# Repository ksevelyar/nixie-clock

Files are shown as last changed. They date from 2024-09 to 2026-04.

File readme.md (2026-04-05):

# Nixie Clock 

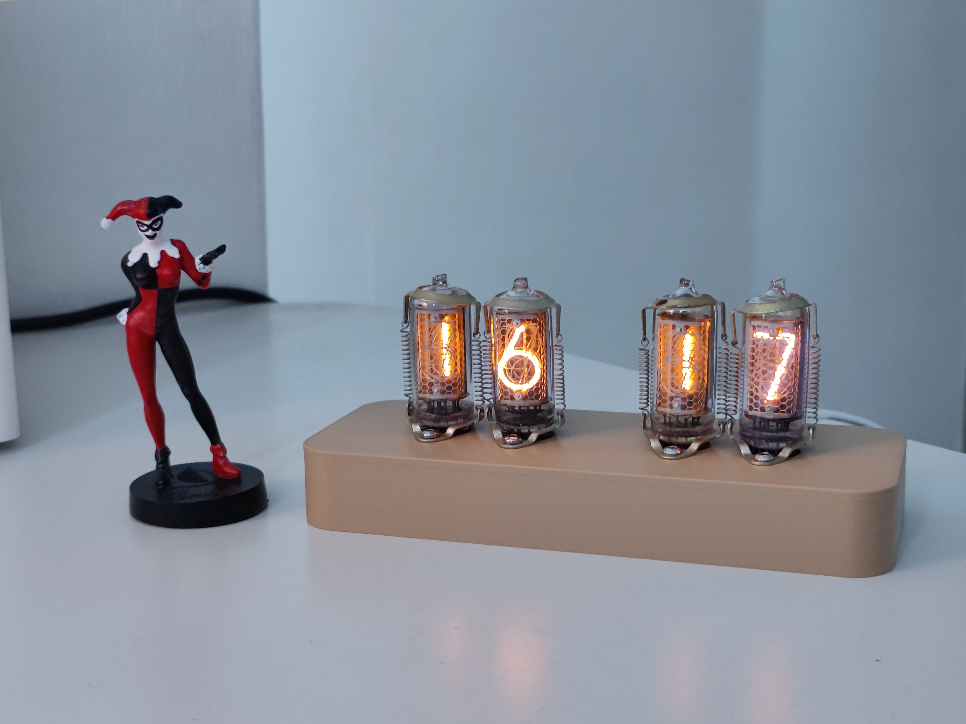
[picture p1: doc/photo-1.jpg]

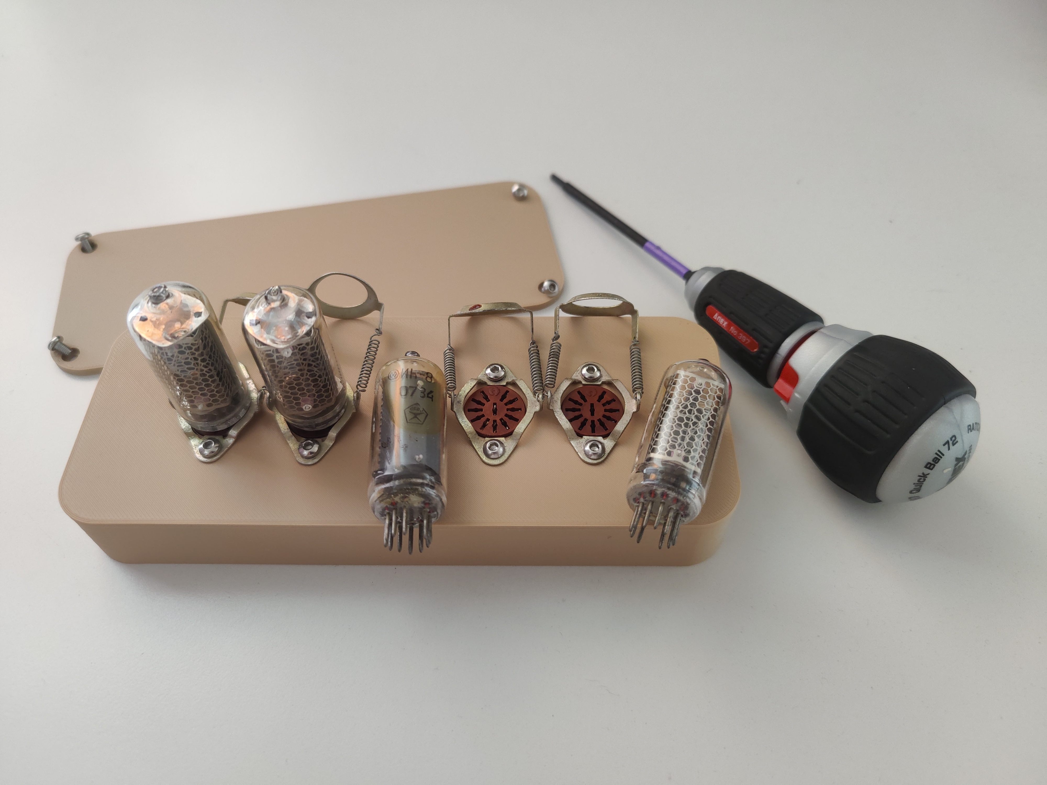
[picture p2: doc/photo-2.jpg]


## Features
- Keeps time in sync via SNTP over Wi‑Fi
- Socketed tubes for quick replacement
- 3D‑printed case
- RISC‑V mcu
- std Rust

## How it works
- On boot, connects to Wi‑Fi and starts SNTP.
- The main loop reads UNIX time, formats HH:MM, and multiplexes four digits.
- GPIO 0–3 carry BCD; GPIO 4–7 select the active digit (one high at a time).
- ~2 ms per digit yields flicker‑free display.

### BCD
```
0 → 0000
1 → 0001
2 → 0010
3 → 0011
4 → 0100
5 → 0101
6 → 0110
7 → 0111
8 → 1000
9 → 1001
```

## Hardware

### Schematic
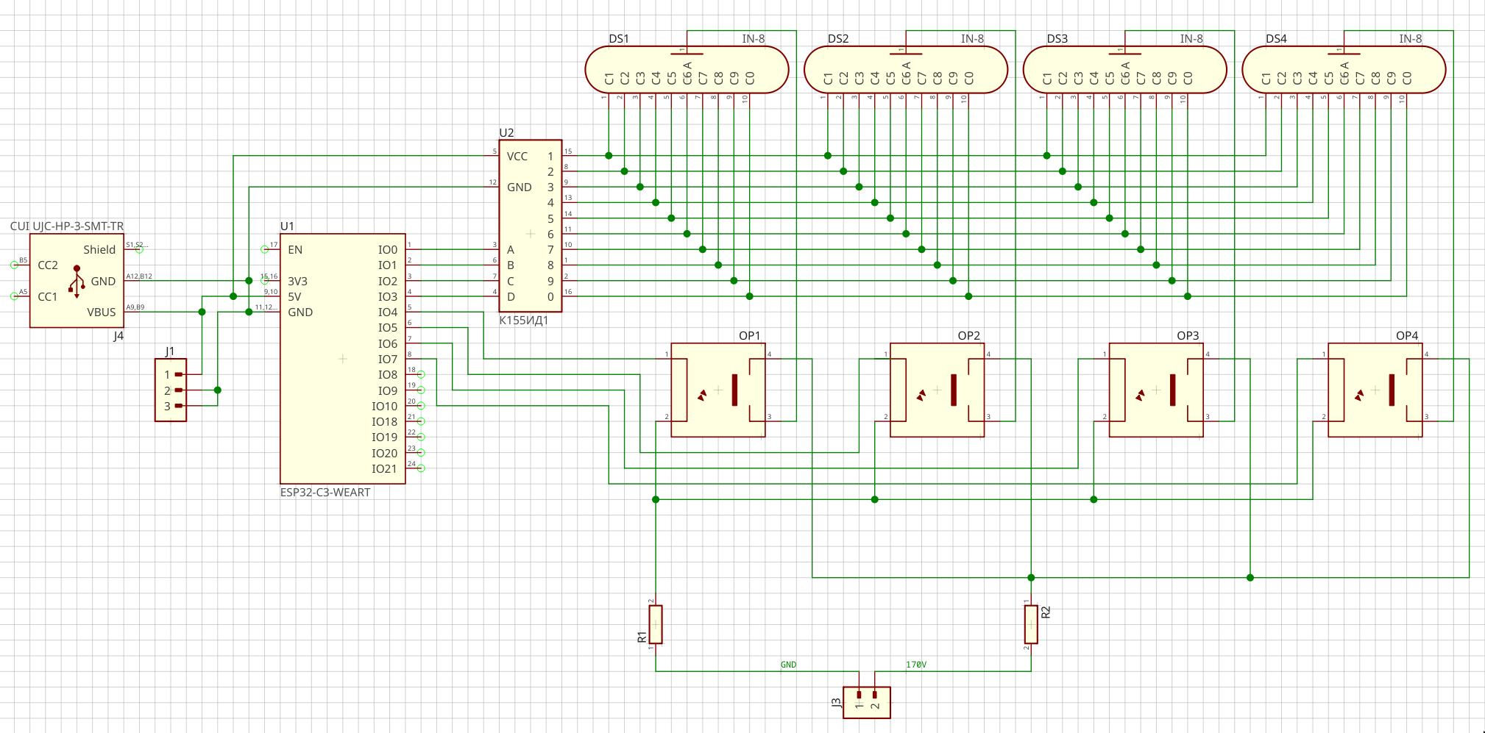
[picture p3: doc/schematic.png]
Schematic


### PCB
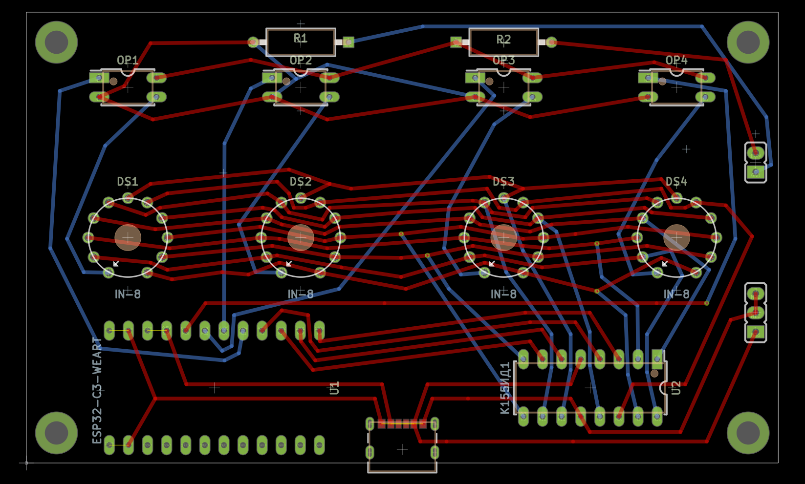
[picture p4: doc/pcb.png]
PCB


## Build & Flash

```fish
nix develop

SSID="WiFi" PASS="Password" UTC_OFFSET=180 cargo run --release
```
```
   Compiling nixie-clock v0.2.0 (/home/ksevelyar/code/nixie-clock)
    Finished `release` profile [optimized] target(s) in 0.67s
     Running `espflash flash --monitor target/riscv32imc-esp-espidf/release/nixie-clock`
[2026-03-31T20:32:43Z INFO ] Serial port: '/dev/ttyACM0'
[2026-03-31T20:32:43Z INFO ] Connecting...
[2026-03-31T20:32:43Z INFO ] Using flash stub
Chip type:         esp32c3 (revision v0.4)
Crystal frequency: 40 MHz
Flash size:        4MB
Features:          WiFi, BLE
MAC address:       60:55:f9:af:93:2c
App/part. size:    1,021,520/4,128,768 bytes, 24.74%
[2026-03-31T20:32:43Z INFO ] Segment at address '0x0' has not changed, skipping write
[2026-03-31T20:32:43Z INFO ] Segment at address '0x8000' has not changed, skipping write
[00:00:12] [========================================]     599/599     0x10000                           [2026-03-31T20:32:57Z INFO ] Flashing has completed!
Commands:
    CTRL+R    Reset chip
    CTRL+C    Exit

...

I (4346) nixie_clock: Wifi DHCP info: IpInfo { ip: 192.168.1.114, subnet: Subnet { gateway: 192.168.1.1, mask: Mask(24) }, dns: Some(192.168.1.1), secondary_dns: Some(0.0.0.0) }

...

I (4366) nixie_clock: SNTP initialized
```

## Update deps
The simplest way is to regenerate a dummy project and copy the dependencies from it:

```
cargo generate esp-rs/esp-idf-template cargo
```

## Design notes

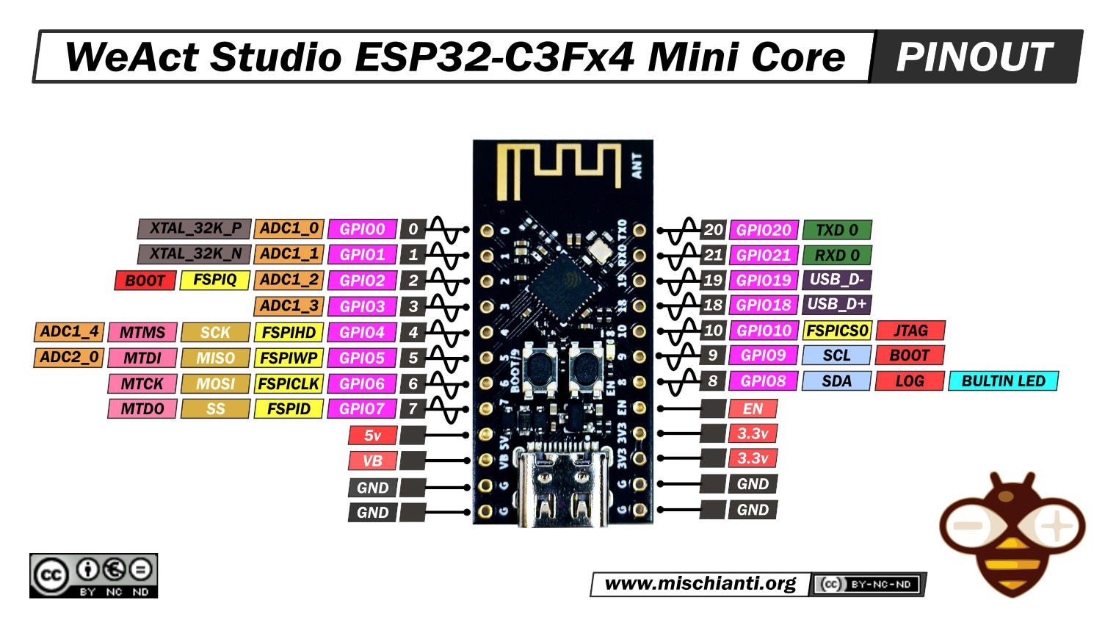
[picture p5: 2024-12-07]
doc/WeAct-Studio-ESP32-C3Fx4-pinout.jpg

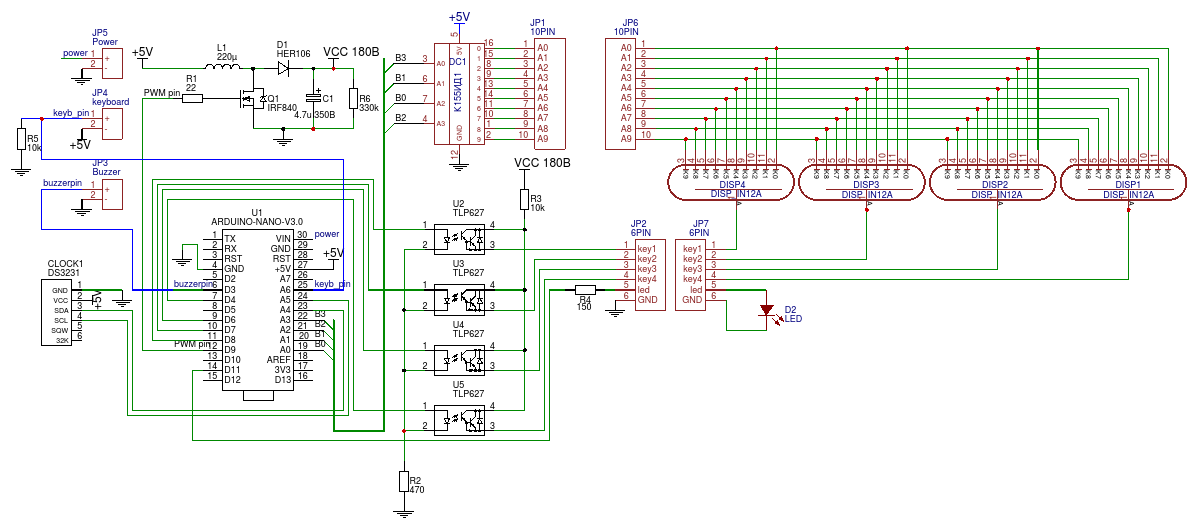
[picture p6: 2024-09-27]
esp32-std/doc/clock-2.png

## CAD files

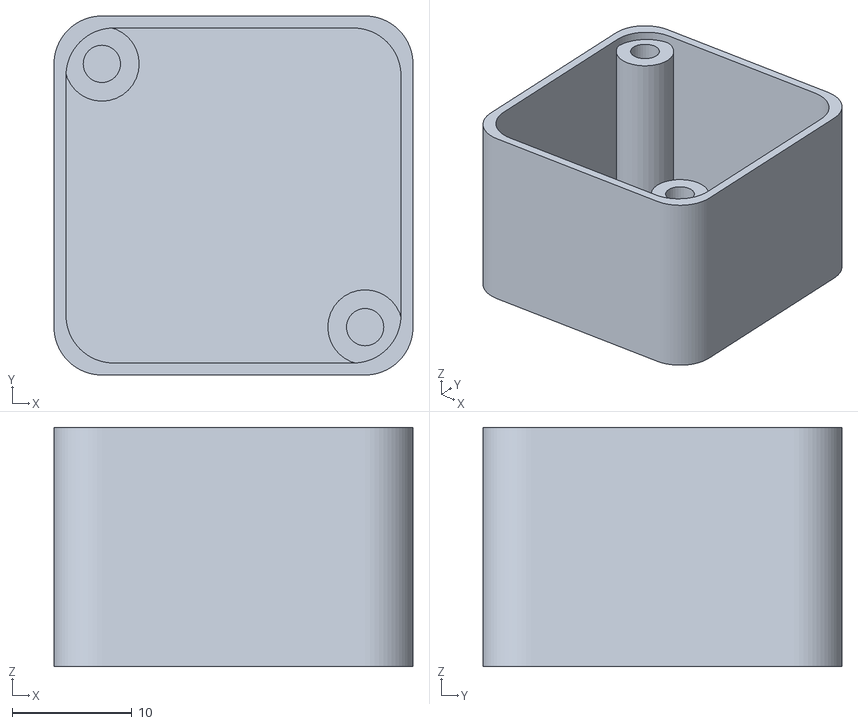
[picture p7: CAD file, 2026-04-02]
case/debug.stl
30.0 x 30.0 x 20.0

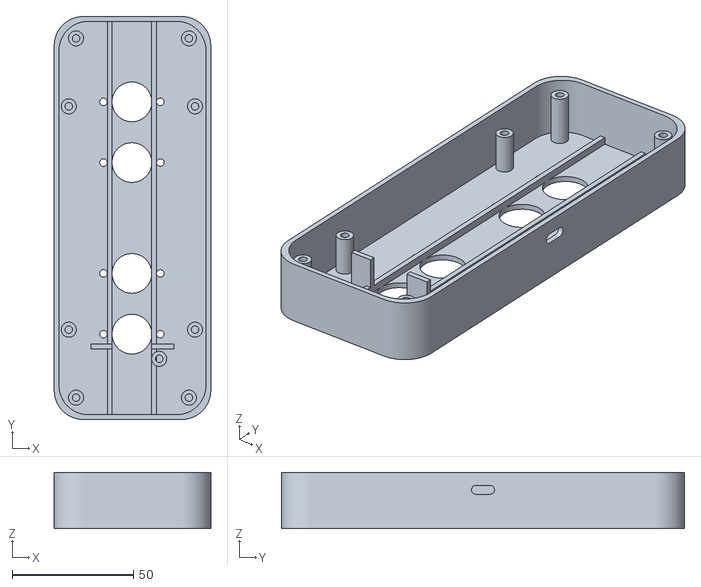
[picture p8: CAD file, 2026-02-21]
case/case.stl
64.5 x 166.0 x 23.2

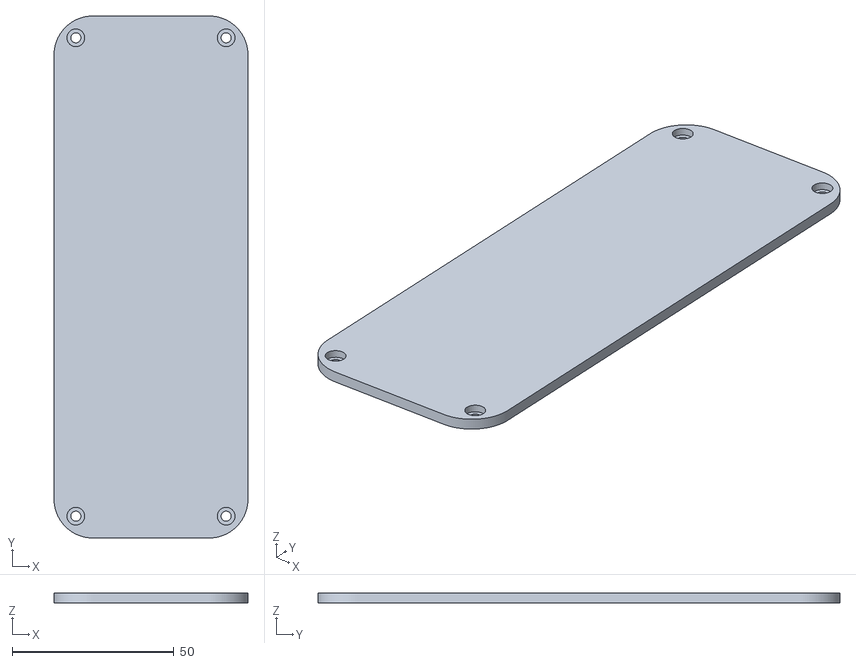
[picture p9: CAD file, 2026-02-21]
case/lid.stl
60.0 x 161.5 x 3.00

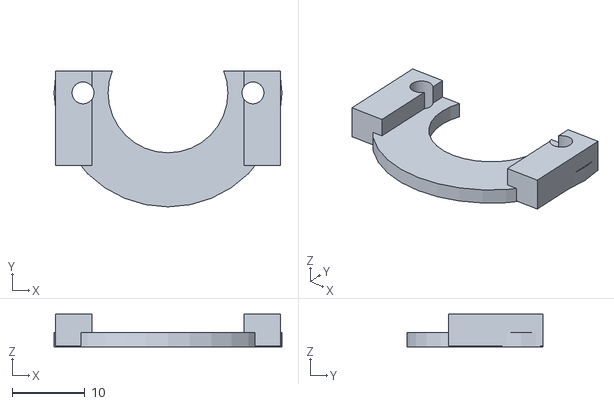
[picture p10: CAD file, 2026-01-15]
case/socket-mount.stl
31.4 x 18.7 x 4.50

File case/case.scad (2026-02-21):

include <mixin.scad>

$fn = 128;

module board() {
  color("#8ec5ff") {
    translate([4, 4, 0]) leg(board_leg_height);
    translate([board_width - 4, 4, 0]) leg(board_leg_height);
    translate([board_width - 4, board_length - 4, 0]) leg(board_leg_height);
    translate([4, board_length - 4, 0]) leg(board_leg_height);
  }
}

module leg(leg_height) {
  difference() {
    cylinder(h=leg_height, d=6.24, $fn=32);
    cylinder(h=leg_height + 1, d=3.12, $fn=32);
  }
}

module tube() {
  translate([board_width / 2, 0, -1])
    cylinder(h=45, d=tube_diameter, $fn=32);

  translate([board_width / 2 + 11.7, 0, -1])
    cylinder(h=45, d=m3, $fn=32);

  translate([board_width / 2 - 11.7, 0, -1])
    cylinder(h=45, d=m3, $fn=32);
}

module tubes() {
  socket_radius = socket_diameter / 2;

  end_gap = (enclosure_length - 4 * socket_diameter) / 3;
  pair_pitch = socket_diameter;

  first_pair_first_center = end_gap + socket_radius;
  second_pair_first_center = first_pair_first_center + 2 * pair_pitch + end_gap;

  tube_centers_y = [
    first_pair_first_center,
    first_pair_first_center + pair_pitch,
    second_pair_first_center,
    second_pair_first_center + pair_pitch,
  ];

  for (center_y = tube_centers_y) translate([0, center_y]) tube();
}

module type_c_cutout() {
  hull() {
    translate(
      [-5, enclosure_length / 2 + 2.9, board_leg_height]
    )
      rotate([0, 90, 0]) cylinder(h=10, d=3.7, $fn=64);
    translate(
      [-5, enclosure_length / 2 - 2.9, board_leg_height]
    )
      rotate([0, 90, 0]) cylinder(h=10, d=3.7, $fn=64);
  }
}

module enclosure() {
  color("#9b8cff") {
    translate([(enclosure_width + wall * 2) / 2 - tube_diameter / 2 - wall - 0.2, wall, 0.1]) cube([2, enclosure_length, 4.6]);
    translate([(enclosure_width - wall / 2) / 2 + tube_diameter / 2 + wall + 0.2, wall, 0.1]) cube([2, enclosure_length, 4.6]);

    difference() {
      rounded_box(
        [enclosure_width + wall * 2, enclosure_length + wall * 2, enclosure_height + lid_height + 0.2],
        r=corner_radius
      );
      translate([wall, wall, wall]) rounded_box(
          [enclosure_width, enclosure_length, enclosure_height * 2], r=corner_radius
        );

      translate([board_width, wall, 0]) type_c_cutout();

      translate([wall, wall, 0]) tubes();
    }

    translate([wall, wall, 0.1]) {
      translate([leg_padding, leg_padding, 0]) leg(enclosure_leg_height);
      translate([enclosure_width - leg_padding, leg_padding, 0]) leg(enclosure_leg_height);
      translate([enclosure_width - leg_padding, enclosure_length - leg_padding, 0]) leg(enclosure_leg_height);
      translate([leg_padding, enclosure_length - leg_padding, 0]) leg(enclosure_leg_height);
    }
  }
}

module regulator() {
  color("#bf7ad1") {
    difference() {
      cube([regulator_width + wall * 2, regulator_length + wall * 2, board_leg_height - wall]);
      translate([-wall, 0, -wall]) cube([regulator_width * 2, regulator_length + wall, 20]);

      translate([(regulator_width - tube_diameter) / 2 + wall - 0.2, 13, -1]) cube([tube_diameter - 0.1, tube_diameter, 18]);
    }

    translate([regulator_width - wall, regulator_length - wall, -0.1]) leg(regulator_leg_height);
  }
}

translate([(enclosure_width - regulator_width) / 2, wall, wall]) regulator();
enclosure();
translate([wall, enclosure_length / 2 - board_length / 2 + wall, 0.1]) {
  board();
}

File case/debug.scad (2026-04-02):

include <mixin.scad>

$fn = 64;
wall = 1;

module board() {
  translate([4, 4, 0]) color("#b1a531") leg(board_leg_height);
  translate([board_width - 4, 4, 0]) color("#b1a531") leg(board_leg_height);
  translate([board_width - 4, board_length - 4, 0]) color("#b1a531") leg(board_leg_height);
  translate([4, board_length - 4, 0]) color("#b1a531") leg(board_leg_height);
}

module leg(leg_height) {
  difference() {
    color("#b1a531") cylinder(h=leg_height, d=6.24, $fn=32);
    cylinder(h=leg_height + 1, d=3.12, $fn=32);
  }
}

module tube() {
  translate([board_width / 2, 0, -1]) color("#d6a731")
      cylinder(h=45, d=tube_diameter, $fn=32);

  translate([board_width / 2 + 11.7, 0, -1]) color("#d6a731")
      cylinder(h=45, d=m3, $fn=32);

  translate([board_width / 2 - 11.7, 0, -1]) color("#d6a731")
      cylinder(h=45, d=m3, $fn=32);
}

module type_c_cutout() {
  hull() {
    translate(
      [-5, enclosure_length / 2 + 2.9, board_leg_height]
    )
      rotate([0, 90, 0]) cylinder(h=10, d=3.7, $fn=64);
    translate(
      [-5, enclosure_length / 2 - 2.9, board_leg_height]
    )
      rotate([0, 90, 0]) cylinder(h=10, d=3.7, $fn=64);
  }
}

module test() {
  enclosure_height = 20 - wall;
  enclosure_leg_height = 20 - wall;

  difference() {
    color("#2f2270") rounded_box(
        [
          30,
          30,
          enclosure_height + wall,
        ],
        r=4
      );
    translate([wall, wall, wall]) rounded_box(
        [30 - wall * 2, 30 - wall * 2, enclosure_height * 2], r=4
      );
  }
  enclosure_width = 30 - wall * 2;
  enclosure_length = 30 - wall * 2;

  translate([wall, wall, 0.1]) {
    translate([enclosure_width - 3, 3, 0]) color("#b1a531") leg(enclosure_leg_height);
    translate([3, enclosure_length - 3, 0]) color("#b1a531") leg(enclosure_leg_height);
  }
}

test();

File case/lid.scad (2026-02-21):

include <mixin.scad>

$fn = 128;

module m3_cutout(height) {
  difference() {
    cylinder(h=height, d=5.5, $fn=32);
    cylinder(h=height + 1, d=3, $fn=32);
  }
}

module cutout(leg_height = 8) {
  cylinder(h=leg_height, d=m3, $fn=32);
}

module lid() {
  difference() {
    translate([wall + 0.25, wall + 0.25, wall]) rounded_box(
        [enclosure_width - 0.5, enclosure_length - 0.5, lid_height], r=corner_radius
      );

    union() {
      translate([wall, wall, 0]) {
        translate([leg_padding, leg_padding, 0]) cutout(enclosure_leg_height);
        translate([enclosure_width - leg_padding, leg_padding, 0]) cutout(enclosure_leg_height);
        translate([enclosure_width - leg_padding, enclosure_length - leg_padding, 0]) cutout(enclosure_leg_height);
        translate([leg_padding, enclosure_length - leg_padding, 0]) cutout(enclosure_leg_height);
      }

      translate([wall, wall, wall + 1]) {
        translate([leg_padding, leg_padding, 0]) m3_cutout(enclosure_leg_height);
        translate([enclosure_width - leg_padding, leg_padding, 0]) m3_cutout(enclosure_leg_height);
        translate([enclosure_width - leg_padding, enclosure_length - leg_padding, 0]) m3_cutout(enclosure_leg_height);
        translate([leg_padding, enclosure_length - leg_padding, 0]) m3_cutout(enclosure_leg_height);
      }
    }
  }
}

lid();

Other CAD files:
case/mixin.scad
case/socket-mount.scad

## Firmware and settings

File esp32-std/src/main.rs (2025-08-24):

use esp_idf_svc::hal::gpio::{Level, PinDriver};
use esp_idf_svc::hal::prelude::Peripherals;
use esp_idf_svc::sntp;
use esp_idf_svc::sys::EspError;
use log::info;

use esp_idf_svc::{eventloop::EspSystemEventLoop, hal::peripheral};

use esp_idf_svc::nvs::*;

const SSID: &str = env!("SSID");
const PASSWORD: &str = env!("PASS");

fn main() -> Result<(), EspError> {
    esp_idf_svc::sys::link_patches();
    esp_idf_svc::log::EspLogger::initialize_default();

    let peripherals = Peripherals::take()?;
    let sysloop = EspSystemEventLoop::take()?;
    let _nvs = EspDefaultNvsPartition::take()?;

    let _wifi = wifi_create(SSID, PASSWORD, peripherals.modem, sysloop)?;
    let mut builtin_led = PinDriver::output(peripherals.pins.gpio8)?;
    builtin_led.set_low()?;

    let _sntp = sntp::EspSntp::new_default()?;
    info!("SNTP initialized");

    let mut pin_a = PinDriver::output(peripherals.pins.gpio0)?;
    let mut pin_b = PinDriver::output(peripherals.pins.gpio1)?;
    let mut pin_c = PinDriver::output(peripherals.pins.gpio2)?;
    let mut pin_d = PinDriver::output(peripherals.pins.gpio3)?;

    loop {
        if let Ok(current_time) = std::time::SystemTime::now().duration_since(std::time::UNIX_EPOCH)
        {
            let seconds = current_time.as_secs() % 60;
            let digit = (seconds % 10) as u8; // last digit of seconds

            info!("Seconds: {:02} -> digit {}", seconds, digit);

            display_digit(&mut pin_a, &mut pin_b, &mut pin_c, &mut pin_d, digit);
        }

        std::thread::sleep(std::time::Duration::from_secs(1));
    }
}

fn display_digit(
    a: &mut PinDriver<'_, esp_idf_svc::hal::gpio::Gpio0, esp_idf_svc::hal::gpio::Output>,
    b: &mut PinDriver<'_, esp_idf_svc::hal::gpio::Gpio1, esp_idf_svc::hal::gpio::Output>,
    c: &mut PinDriver<'_, esp_idf_svc::hal::gpio::Gpio2, esp_idf_svc::hal::gpio::Output>,
    d: &mut PinDriver<'_, esp_idf_svc::hal::gpio::Gpio3, esp_idf_svc::hal::gpio::Output>,
    digit: u8,
) {
    let bcd = [
        digit & 0b0001 != 0,
        digit & 0b0010 != 0,
        digit & 0b0100 != 0,
        digit & 0b1000 != 0,
    ];

    a.set_level(if bcd[0] { Level::High } else { Level::Low }).unwrap();
    b.set_level(if bcd[1] { Level::High } else { Level::Low }).unwrap();
    c.set_level(if bcd[2] { Level::High } else { Level::Low }).unwrap();
    d.set_level(if bcd[3] { Level::High } else { Level::Low }).unwrap();
}

fn wifi_create(
    ssid: &str,
    pass: &str,
    modem: impl peripheral::Peripheral<P = esp_idf_svc::hal::modem::Modem> + 'static,
    sysloop: EspSystemEventLoop,
) -> Result<esp_idf_svc::wifi::EspWifi<'static>, EspError> {
    use esp_idf_svc::wifi::*;

    //let mut esp_wifi = EspWifi::new(modem, sysloop.clone(), Some(nvs.clone()))?;
    let mut esp_wifi = EspWifi::new(modem, sysloop.clone(), None)?;
    let mut wifi = BlockingWifi::wrap(&mut esp_wifi, sysloop.clone())?;

    wifi.set_configuration(&Configuration::Client(ClientConfiguration {
        ssid: ssid.try_into().unwrap(),
        password: pass.try_into().unwrap(),
        ..Default::default()
    }))?;

    wifi.start()?;
    info!("Wifi started");

    wifi.connect()?;
    info!("Wifi connected");

    wifi.wait_netif_up()?;
    let ip_info = wifi.wifi().sta_netif().get_ip_info()?;
    info!("Wifi DHCP info: {:?}", ip_info);

    Ok(esp_wifi)
}

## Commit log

2024-11-13 build dc booster with pwm on PA0
2024-11-23 add esp32
2024-12-07 implement i2c scanner
2025-08-24 get the last digit of seconds from current time; encode it with k155id1
2025-08-30 add case
    [case.scad]
2025-08-30 clean up structure
    [case.scad]
2025-09-13 case: add regulator
    [case.scad]
2025-09-15 case: initial test stand
    [case.scad]
2025-09-16 case: add lid
    [case.scad, case.stl, lid.scad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]
2025-09-17 case: rounded corners
    [case.scad, case.stl, lid.scad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]
2025-09-22 update case
    [case.scad, case.stl, lid.scad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]
2025-11-23 fix timezone, fix digits order, use FreeRTOS-aware delay
    [main.rs]
2025-11-25 update case, add maybe_update_state()
    [case.scad, case.stl, lid.scad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]
2025-12-07 update case; update rust
    [case.scad, case.stl]
2026-01-15 change socket mount
    [case.scad, socket-mount.scad, socket-mount.stl]
2026-01-17 simplify case and parameterize corner radius
    [case.scad, case.stl, lid.scad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]
2026-02-22 fix error in optocouplers wiring
2026-04-02 add debug.stl
    [debug.scad, debug.stl]
